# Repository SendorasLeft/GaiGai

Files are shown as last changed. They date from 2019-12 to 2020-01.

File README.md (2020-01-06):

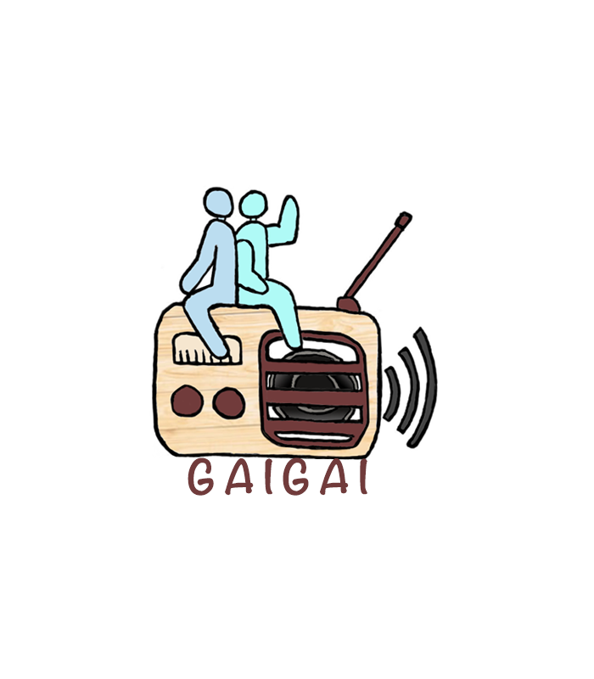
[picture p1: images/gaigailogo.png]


# GaiGai: A Radio for the Soul

Listen. Reconnect. Empower.

## The Team

Hello! We are Team GaiGai, consisting of:

- Yijie (Computer Science)
- Yong Hao (Materials Science & Engineering)
- Sharon (Pharmacy)
- Yong Kuan (Engineering Science Programme)

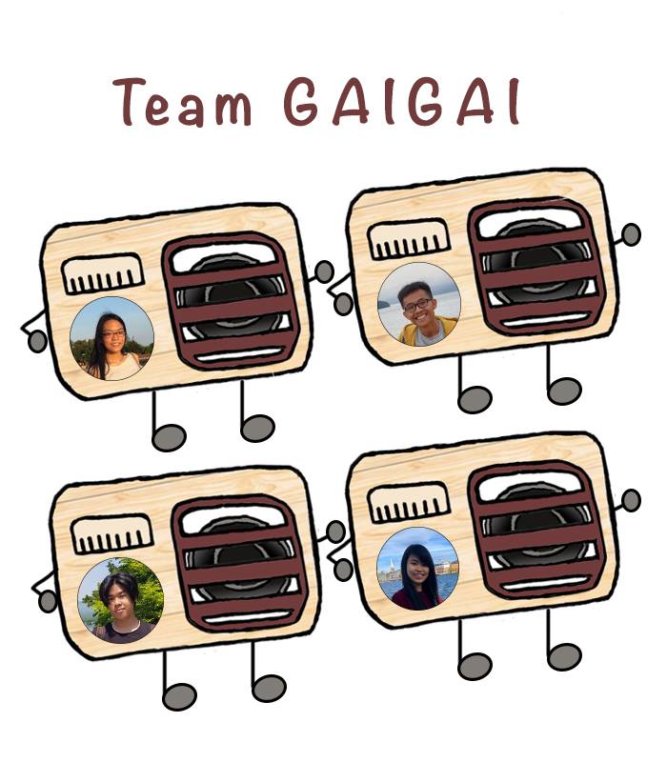
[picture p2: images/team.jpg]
team


## What is our purpose?

Our creation, the **GaiGai Radio**, aims to bridge the social gap between isolated
elderlies and their communities by gently surrounding them with the sounds of
a bustling community. Even if they live alone, this radio
ensures that they will never again be subject to the crippling silence of
solitude within their own homes.

## What exactly is the GaiGai Radio?



The GaiGai Radio is exactly what it sounds like - it's a radio that live-streams
various channels for the user to tune in to. But here's the twist: instead of
just listening to radio stars broadcasting their one-man shows, **everyone** who has a GaiGai Radio
can choose to participate in these streams. From everyday sounds to conversation or jokes,
these radios provide a platform for elderlies to reach out or keep in touch with others
who may be living near them. Over time, these radios aim to provide a stress-free
and convenient way to help isolated elderlies open up to their nearby communities, integrating them
back into society.

This radio:

- lets an elderly tune in to all available channels on a local server
- enables him / her to broadcast their own voice over the current channel
- is highly portable and can be easily carried around
- respects your privacy: the microphone can be easily muted with a click of a button!
- is fully anonymous and provides encryption over TCP-based VoIP communication servers
- **does not actually need to be in the form of a radio at all!** We provide an alternative
  way to simply run it using any computer with the correct dependencies

And most of all, everything from the hardware to software is entirely open-source, and easy to make.

## How does it work?

The GaiGai radio functions through a server-client architecture: in the public implementation, once
a radio is turned on, it first seeks out a central server to query for all available nearby servers
in the radio's vicinity. Thereafter, once it receives a suitable server, it attempts to connect and
tunes the user into the first available channel. The streaming is handled via an open-source
VoIP implementation known as [Murmur](https://github.com/mumble-voip/mumble/tree/master/src/murmur),
and streaming is done using TCP to the client radio.

To simplify things for this setup guide, however, we will teach you how to create your own server and radio from scratch. The
radio will then directly connect to the server, which can be run on any suitable computing device.

## How do I make my own GaiGai Radio?

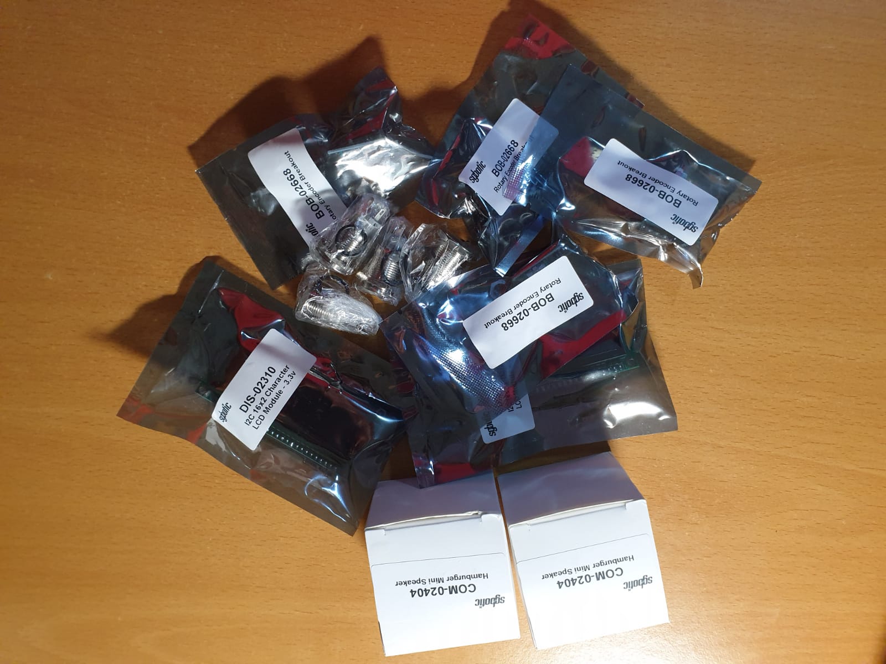
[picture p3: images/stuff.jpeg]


### Components

For a physical radio, you will need the following:

- 1 x Raspberry Pi Model 3 B
- 2 x Rotary encoders (One for the volume button, one for switching channels)
- 2 x 5V latching buttons (Power on/off switch, microphone mute)
- 1 x I2C LCD screen
- 1 x Jack-in Speaker
- 1 x Breadboard
- 1 x Blu Tack
- 1 x External PowerBank
- 1 x USB Microphone (we recommend using a [boundary or conference microphone](https://en.wikipedia.org/wiki/Boundary_microphone))
- Velcro, tape, and foam to hold the internal components together
- A 3D printer for the external casing (or some cardboard crafting skills!)
- (Optional) Acrylic paint, to jazz up the radio's exterior
- (Optional) Small pouch to hold the microphone if your chosen mic is limply wired, or if you opt for
  earphones
- (Optional) Velcro and slingband to act as a handle / strap for carrying the radio around

For the server, you will need the following:

- Minimally, a local network for hosting streams
- A computing device to run as the server. In this case, we use another Raspberry Pi 4 to fulfill this role.
- Internet connection, if hosting the server over the internet

### Physical Casing

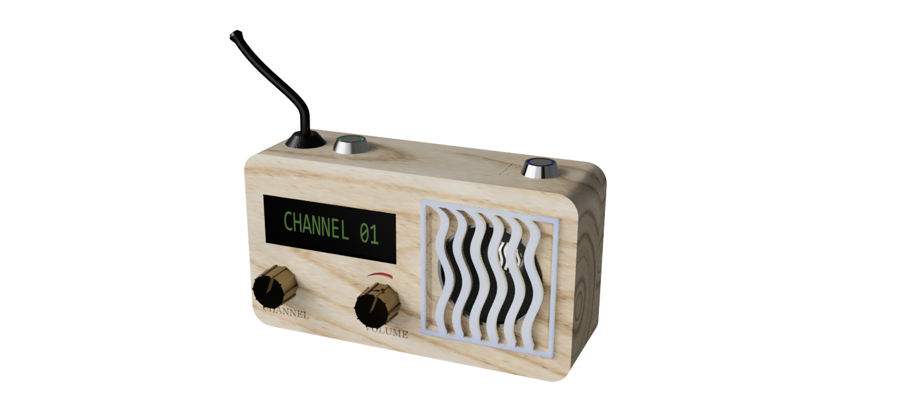
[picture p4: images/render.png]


We have released the STL files that we used for 3D-printing the exterior radio casing in the
[GitHub repository](https://github.com/SendorasLeft/GaiGai). Do feel free to use them, or modify
as necessary based on your chosen hardware dimensions. These files contain CAD models for the following:

- Front Casing
- Back Casing
- Rotary Knob Casings

If a
3D printer is not available, you may also make them out of other materials like cardboard.
(We do actually have a very decent alternate version of the radio
that was made from cardboard, so we're not pulling your leg here)

After making the case, put your artistic skills to the test by decorating the case!
We personally recommend a wooden texture.

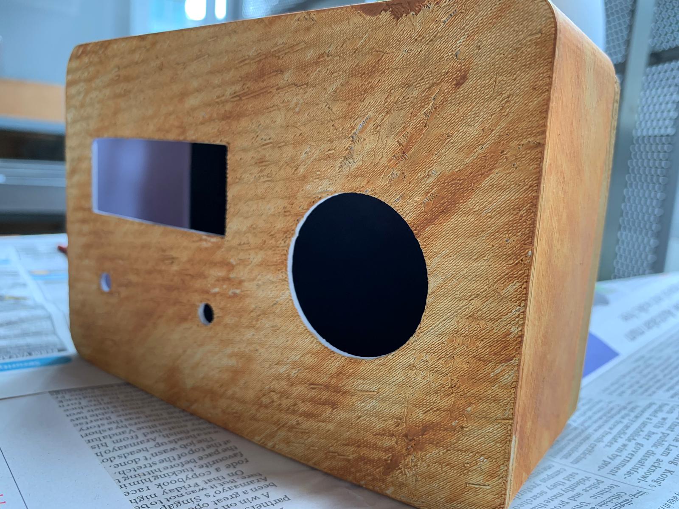
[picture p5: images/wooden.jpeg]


### Hardware Connections

We first need to wire up all the necessary components. Here is a full connection diagram you can follow
for the rotary encoders and latching buttons used for the radio:

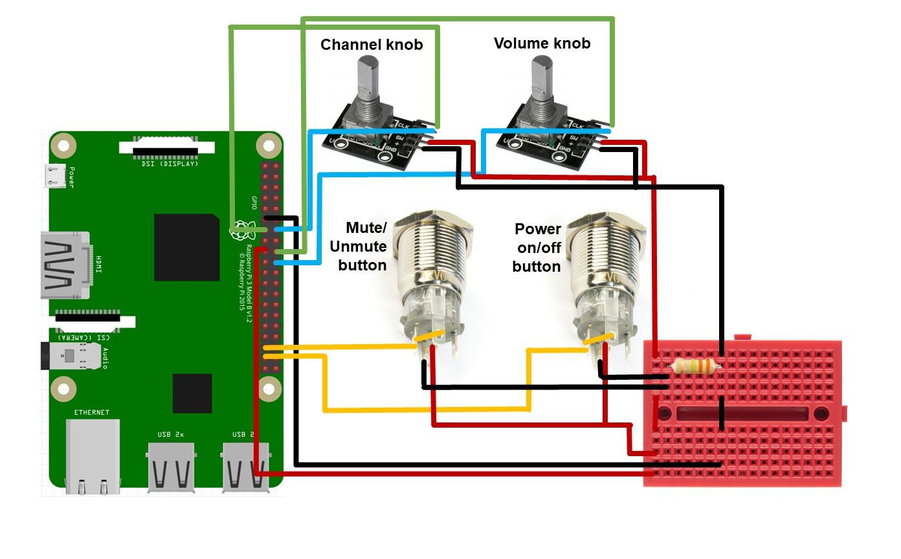
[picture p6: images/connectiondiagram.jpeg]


In addition, we also need to set up the connections for the LCD screen. This portion
is going to be a little more complicated, but you can
You can follow [this
instructive guide](http://www.circuitbasics.com/raspberry-pi-i2c-lcd-set-up-and-programming/).

The connection diagram for the I2C LCD screen should look like the following. This can differ depending on your
exact model.

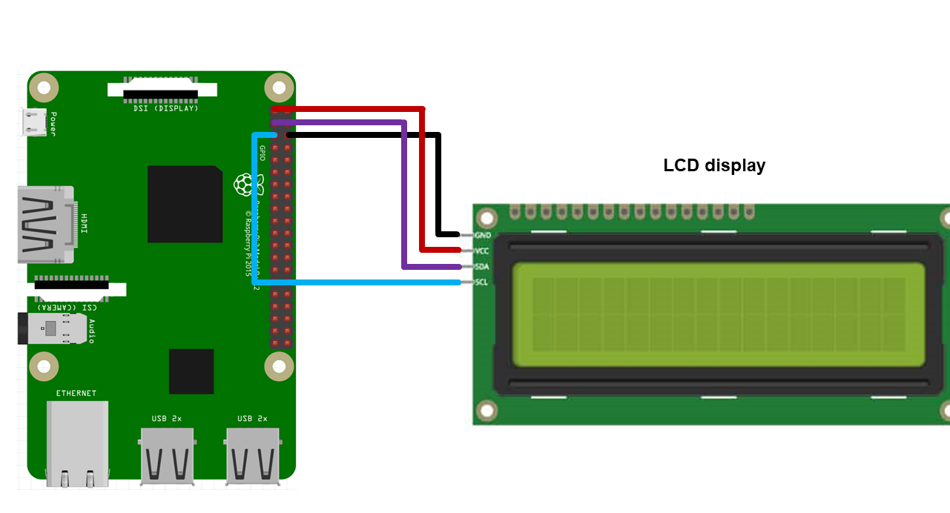
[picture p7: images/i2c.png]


Lastly, remember to connect up your chosen microphone and speaker.

### Setting up the Server

**Pre-requisites:**

- A Raspberry Pi with a flashed OS. If you're not sure how to do this step,
  the Raspberry Pi Foundation has a great
  starting guide [here](https://www.raspberrypi.org/downloads/). Alternatively, you may also wish to check
  out the [Murmur](https://github.com/mumble-voip/mumble/tree/master/src/murmur) documentation if you want
  to set up the server on an alternate computing device.
- Connect to a suitable WiFi / ethernet port with local network or internet access

**Set up the server:**

1. First, install the server dependencies by running `sudo apt-get install mumble-server`
2. Then, configure the autostart daemon by typing: `sudo dpkg-reconfigure mumble-server`. Choose yes to the following:
   - "AutoStart": Boot server on Pi startup
   - "High Priority": Dedicate available resources to running the server if possible
   - "SuperUser": Enables the `SuperUser` admin account, which can help you to configure the server
3. Find out the ip address of your Pi. (Use the `ifconfig` command to help you)
4. Set the password for the admin account `SuperUser`
   - run `sudo /usr/sbin/murmurd -ini /etc/mumble-server.ini -supw <password>`
5. Thereafter, configure your server details by running `sudo nano /etc/mumble-server.ini`
   - There are many things you can configure here. If you have time, we recommend that you take
     a good look through many of the variables in this file since they are pretty self-explanatory and offer
     some powerful customizations over the server. We suggest a few important ones below:
   - `Ctrl+W`, then type `mumble server` to jump to the relevant section. Uncomment it and replace with
     the name of your server
   - `Ctrl+W`, then type `port` to locate the relevant section. By default the server will be started on
     port `64738`. Change this if you wish to host the server on a different port (make sure you avoid the reserved ports!)
   - `Ctrl+W`, then type `channel`to locate the relevant section. This is where you can default channels to the server.
6. Finally, run `sudo /etc/init.d/mumble-server restart` to restart the server with the new settings. If all of
   the above was followed, the server should start anytime the Raspberry Pi is switched on.
7. (Optional) Set up port forwarding for global internet access to your server. Look up the instructions for your router model, and forward all messages
   from your desired port to the IP address of the mumble server (which should have been discovered Step 3)
8. (Optional) Login as the SuperUser admin account to configure the server via [Mumble](https://www.mumble.com/mumble-download.php). This is for those
   who don't like to browse through the configuration settings in Step 5.

### Setting up the Radio Software Backend

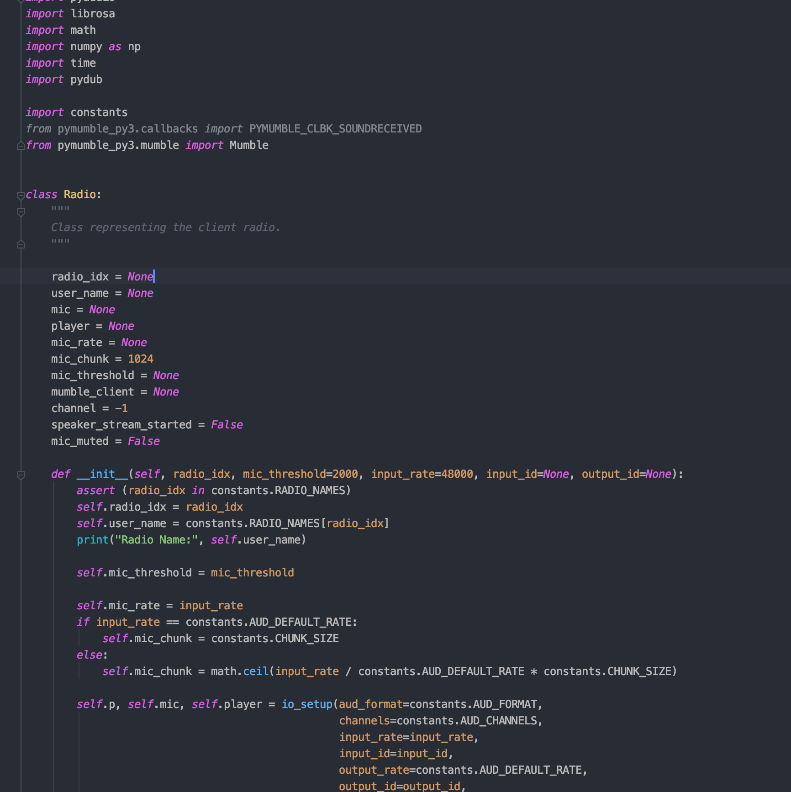
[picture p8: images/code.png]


**Pre-requisites:**

- A Raspberry Pi 3 Model B with a flashed OS. If you're not sure how to do this step,
  the Raspberry Pi Foundation has a great
  starting guide [here](https://www.raspberrypi.org/downloads/).

Note: For simplification in this setup guide, we hard-code the the server details in `constants.py`.
Change them there if required (for example, if you set a different port or IP for your server). This
guide assumes that five channels were created on the server.

**Install Dependencies:**
Here, we install all packages needed to run the radio.

- Update package lists
  - `sudo apt-get update`
  - `sudo apt-get dist-upgrade`
- PortAudio (purpose: audio streaming)
  - `sudo apt-get install libasound-dev`
  - `sudo apt-get install portaudio19-dev`
- PyAudio (purpose: audio streaming)
  - `sudo pip3 install pyaudio`
  - `sudo apt-get install python3-pyaudio`
- librosa (purpose: audio resampling & compression)
  - `sudo apt install libblas-dev llvm python3-pip python3-scipy`
  - `sudo apt install python3-protobuf`
  - `sudo pip3 install numpy --upgrade`
  - `sudo apt-get install python3-pandas`
  - `sudo apt-get install python3-sklearn`
  - `sudo apt-get install libatlas-base-dev`
  - `sudo pip3 install librosa==0.4.2`
- pydub (purpose: audio stream mixing)
  - `sudo pip3 install pydub`
- pyalsaaudio (purpose: volume control)
  - `sudo pip3 install pyalsaaudio`

**NOTE: Do not install or clone the pymumble library directly. We use a slightly modified version of
the written pymumble API for efficiency, which is included in this repository itself.**

**Clone the repository:**

Of course, we need to get the actual radio scripts for our radio. Here, we clone
it into the home directory of the Raspberry Pi.

- `cd ~`
- `git clone https://github.com/SendorasLeft/GaiGai`

**Headless setup:**

Since the Raspberry Pi will run inside the radio, it does not need to boot into
a fancy GUI. Here are the steps that will allow it to boot directly into the terminal:

- `raspi-config`
- Go to Boot Options, then select the option to boot into terminal **without** a password

**Run radio script on startup:**

Finally, we configure the python3 script to run on startup. There are many ways to do this, but
the simplest way is to add it to your bashrc confiuration file, since we're starting the RPi in
headless mode anyway.

- `echo "sudo python3 ~/GaiGai/driver_client.py <RADIO_IDX>" >> ~/.bashrc`
- Note: Replace `<RADIO_IDX>` above with an integer from 0 to 5. You can add more IDs via
  the `constants.py` file.

**Alternative: Run on Linux computer without hardware**

We provide a simplified script to start the radio on a computer if you do not wish to start
up the hardware. Note that at this point, the script does not support hardware functions like
channel switching or volume control etc. - To start the script, run `python3 driver_pc.py <RADIO_IDX>`

And you're done with the RPi software setup! The only thing left to do now is to bring it all together.

### Bringing It Altogether

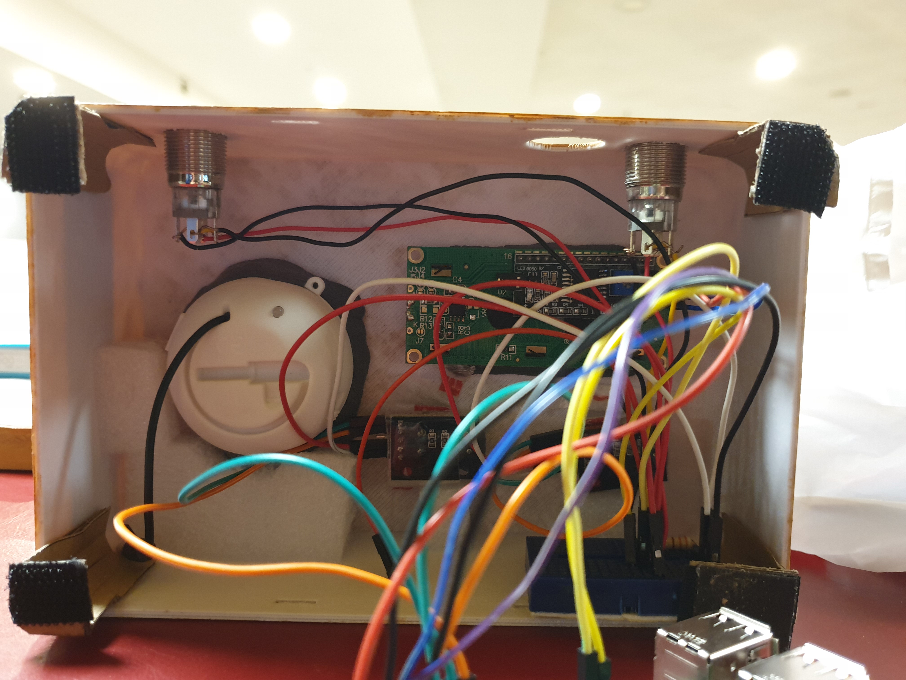
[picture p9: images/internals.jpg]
internals


Fit all the electronics within the case. There really isn't much we can do to guide you here, but
here are a few tips:

- Use blu-tack to fit the electronic components like the LCD screen or latching buttons
  into their grooves
- Use a layer of acrylic tape to hold electronics down after they are secured
- Use packing foam to further support the electronics and fill up empty spaces
- Use Velco with cardboard to create latching handles for the back case to attach to the front
- Fit all the electronic accessories inside first, then connect them to the Raspberry Pi towards the end.
- Don't forget to connect the power bank, microphone, and speaker before you close up the radio.
- (Optional) Use Velcro to tape on a suitable strap for carrying the radio around!
- (Optional) Use Velcro to tape on a suitable back pouch at the backc of the radio for holding small items

And there you have it, your own **GaiGai Radio**!

showcase

## Credits

This project is licensed under the [GNU General Public License v3.0](LICENSE).

We would also like to thank the maintainers of the open-source VoIP server project
[Murmur / Mumble](https://github.com/mumble-voip/), as well as its corresponding [client-side
python library](https://github.com/azlux/pymumble) which was started by [Robert904](https://github.com/Robert904), and actively maintained by [azlux](https://github.com/azlux) in a fork.

Lastly, we would like to express our gratitude to NUS and the organizers of
[NUS Makerthon 2020](https://blog.nus.edu.sg/makerthon2020/competition-theme/), without
whom this project would not have been possible.

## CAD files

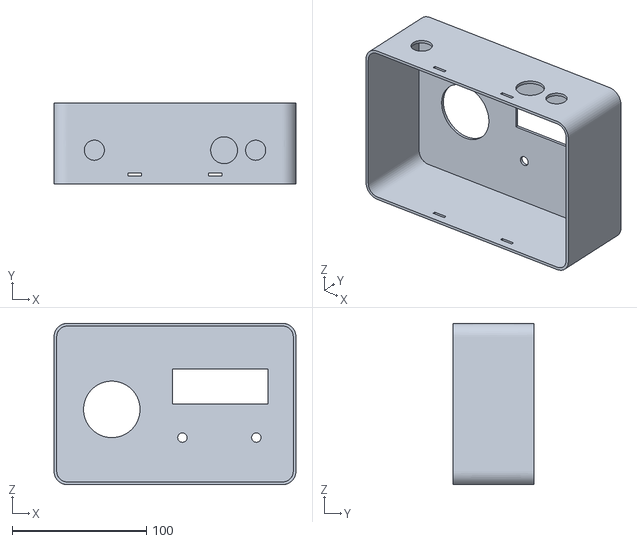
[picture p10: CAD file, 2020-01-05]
casing stl/radio_upsize_front.stl
180.0 x 60.0 x 120.0

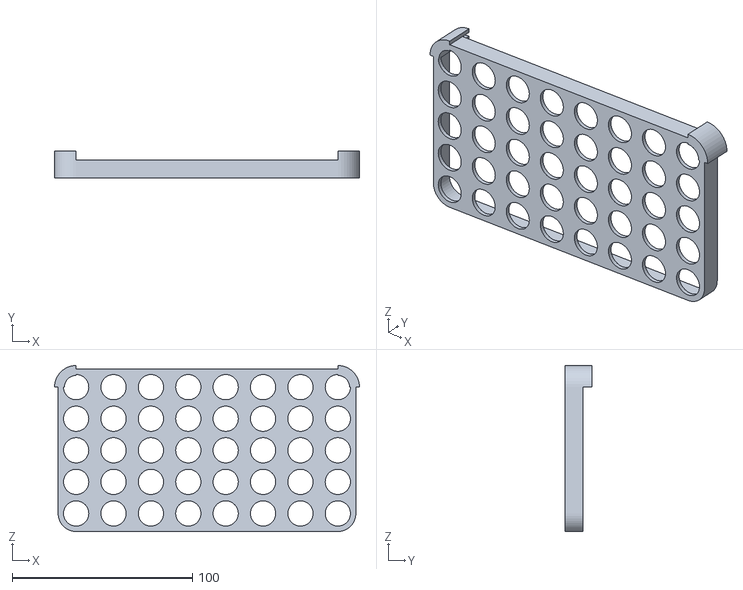
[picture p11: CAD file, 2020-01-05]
casing stl/radioback_v1.stl
169.0 x 15.0 x 92.0

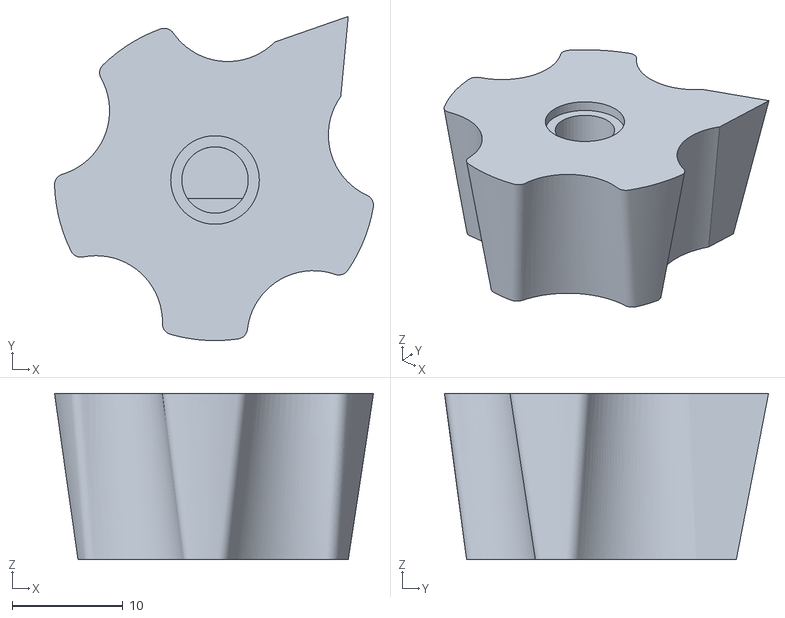
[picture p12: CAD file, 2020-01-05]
casing stl/radio_knob.stl
28.8 x 29.3 x 15.0

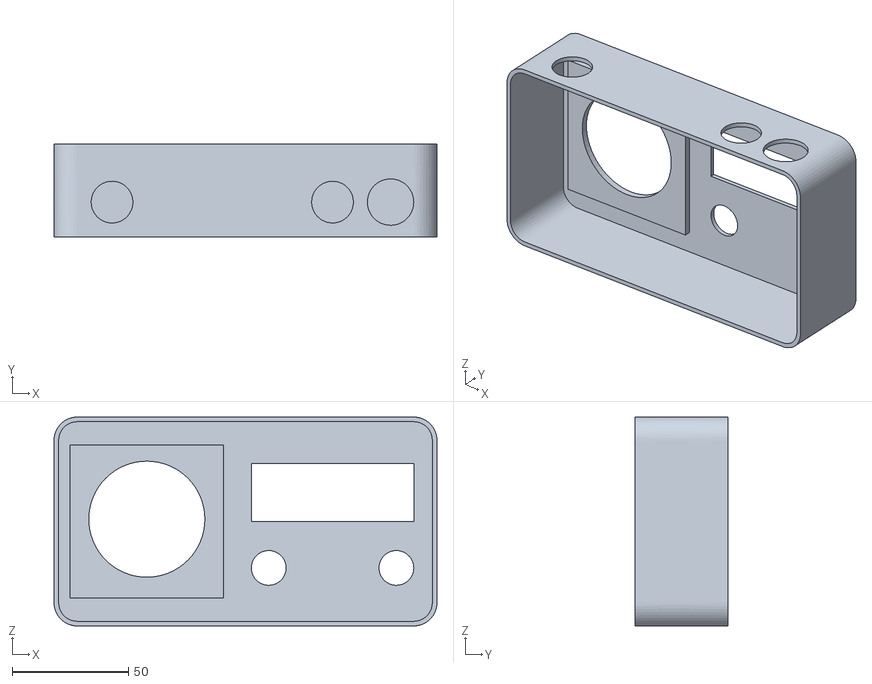
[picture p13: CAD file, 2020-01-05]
casing stl/radiofront_v1.stl
165.0 x 40.0 x 90.0

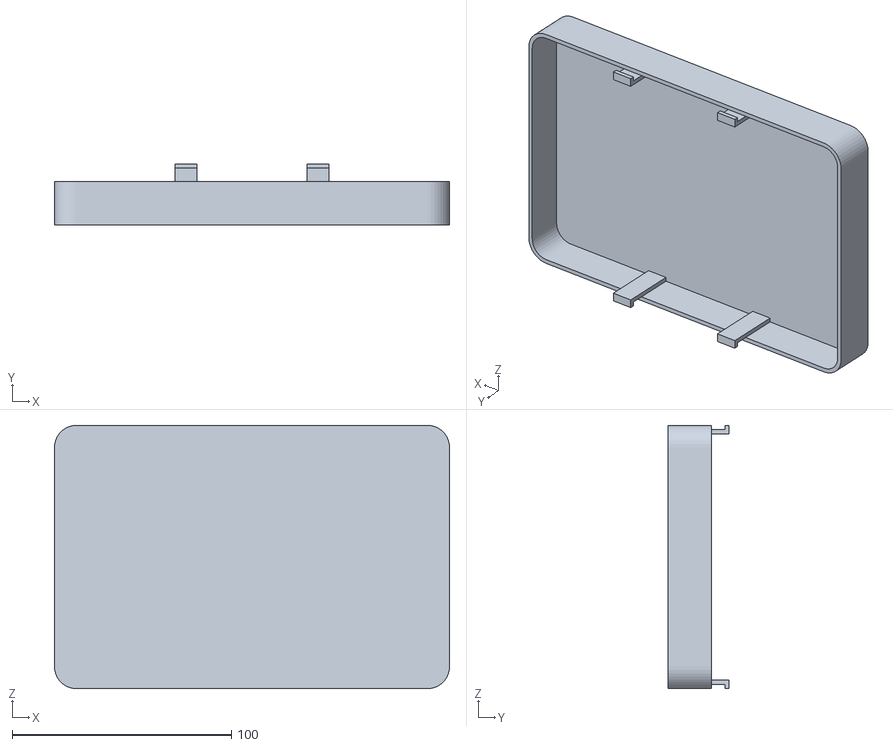
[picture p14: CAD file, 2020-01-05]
casing stl/radio_upsize_back.stl
180.0 x 28.0 x 120.0

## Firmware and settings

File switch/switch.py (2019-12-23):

from RPi import GPIO
from time import sleep

def setup(button):
    GPIO.setmode(GPIO.BCM)
    GPIO.setup(button, GPIO.IN, pull_up_down=GPIO.PUD_DOWN)

def loop(button):
    lastState = False
    while True:
        buttonState = GPIO.input(button)
        if buttonState != lastState:
            if buttonState == True:
                print("Button Pressed...")
            else:
                print("Button not pressed...")
        lastState = buttonState
        sleep(0.2)

def endProgram():
    GPIO.cleanup()

def main():
    button = 19
    setup(button)
    try:
        loop(button)
    except KeyboardInterrupt:
        print("keyboard interrupt detected")
        endProgram()

if __name__ == '__main__':
    main()

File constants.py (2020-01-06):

import pyaudio
import wave
from collections import namedtuple

# radio_idx to username mappings
RADIO_NAMES = {
    1: "RadioOne",
    2: "RadioTwo",
    3: "RadioThree",
    4: "RadioFour",
    5: "RadioFive",
    6: "RadioSix",
    7: "RadioSeven"
}

CHANNELS = [1, 5, 3, 4, 6]

# pyaudio
AUD_FORMAT = pyaudio.paInt16
AUD_CHANNELS = 1
AUD_DEFAULT_RATE = 48000

# packet chunk
CHUNK_SIZE = 1024

# server details TODO: define new channels
ServerDetails = namedtuple("ServerDetails",
                           "password address port")
SERVERS = {
    0: ServerDetails(password="password",
                     address="192.168.43.130",
                     port=64738),
    1: ServerDetails(password="password",
                     address="192.168.43.130",
                     port=64738),
    2: ServerDetails(password="password",
                     address="192.168.43.130",
                     port=64738)
}

CHUNK = 1024

CH_POWERON = "./voice/chinese/poweron.wav"
CH_POWEROFF = "./voice/chinese/poweroff.wav"
CH_CHNL0 = "./voice/chinese/chnl0.wav"
CH_CHNL1 = "./voice/chinese/chnl1.wav"
CH_CHNL2 = "./voice/chinese/chnl2.wav"
CH_CHNL3 = "./voice/chinese/chnl3.wav"
CH_CHNL4 = "./voice/chinese/chnl4.wav"
CH_MUTE = "./voice/chinese/muted.wav"
CH_UNMUTE = "./voice/chinese/unmuted.wav"

EN_POWERON = "./voice/english/poweron.wav"
EN_POWEROFF = "./voice/english/poweroff.wav"
EN_CHNL0 = "./voice/english/chnl0.wav"
EN_CHNL1 = "./voice/english/chnl1.wav"
EN_CHNL2 = "./voice/english/chnl2.wav"
EN_CHNL3 = "./voice/english/chnl3.wav"
EN_CHNL4 = "./voice/english/chnl4.wav"
EN_MUTE = "./voice/english/muted.wav"
EN_UNMUTE = "./voice/english/unmuted.wav"

CHNL0 = [EN_CHNL0, CH_CHNL0]
CHNL1 = [EN_CHNL1, CH_CHNL1]
CHNL2 = [EN_CHNL2, CH_CHNL2]
CHNL3 = [EN_CHNL3, CH_CHNL3]
CHNL4 = [EN_CHNL4, CH_CHNL4]

# BILINGUAL NOTIFICATION
POWERON = [EN_POWERON, CH_POWERON]
POWEROFF = [EN_POWEROFF, EN_POWEROFF]
CHNLS = [CHNL0, CHNL1, CHNL2, CHNL3, CHNL4]
MUTE = [EN_MUTE, CH_MUTE]
UNMUTE = [EN_UNMUTE, CH_UNMUTE]

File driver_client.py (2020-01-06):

import sys

from threading import Thread
from multiprocessing import Process
from time import sleep, time
from RPi import GPIO

from radio import Radio
# from knob.rotary_encoder import volume_main
import RPI_I2C_driver
# from lcd.channel_display import controlChannel

from gpiozero import Button
from knob.vol_control import changeVol, getVol
from knob.channel_control import changeChannel
from lcd.formatString import formatString
from switch.lcd_start_stop import display
from constants import *

INPUT_RATE = 48000
INPUT_ID = None
OUTPUT_ID = None

MIC_THRESHOLD = 2000

# rotary encoder
VOL_PIN_A = 23
VOL_PIN_B = 24

CHNL_PIN_A = 17
CHNL_PIN_B = 18

# switch
POWER_PIN = 26
MUTE_PIN = 19

radio = None
lastUpdateTime = 0
channel = 0
screen = RPI_I2C_driver.lcd()
screen.backlight(0)
power = False # True

volControlA = Button(VOL_PIN_A, pull_up=True)
volControlB = Button(VOL_PIN_B, pull_up=True)
chnlControlA = Button(CHNL_PIN_A, pull_up=True)
chnlControlB = Button(CHNL_PIN_B, pull_up=True)


def write_status():
    screen.lcd_display_string("Vol:"
                              + str(getVol()), 2)

def volcw():
    if power == True and volControlA.is_pressed:
        # print("1")
        changeVol(1)

def volccw():
    if power == True and volControlB.is_pressed:
        # print("-1")
        changeVol(0)

def chnlcw():
    global lastUpdateTime, channel
    if power == True and chnlControlA.is_pressed:
        print("1")
        newChnl = changeChannel(1, channel) # return channel number
        lastUpdateTime = time()
        channel = newChnl
        screen.lcd_display_string(formatString("Channel " + str(newChnl)), 1)
        # radio.change_channel(newChnl)
        

def chnlccw():
    global lastUpdateTime, channel
    if power == True and chnlControlB.is_pressed:
        print("-1")
        newChnl = changeChannel(0, channel) # return channel number
        lastUpdateTime = time()
        channel = newChnl
        screen.lcd_display_string(formatString("Channel " + str(newChnl)), 1)
        # radio.change_channel(newChnl)

# power on off
def switchedOn():
    global power
    print("on")
    display(1)
    radio.play_bilingual_notification(POWERON)
    power = True

def switchedOff():
    global power
    print("off")
    display(0)
    radio.play_bilingual_notification(POWEROFF)
    power = False
    
def muteMic():
    if power == True:
        radio.mute_mic()
        radio.play_bilingual_notification(MUTE)
    
def unmuteMic():
    if power == True:
        radio.unmute_mic()
        radio.play_bilingual_notification(UNMUTE)

# def GPIOsetup(clk, dt):
#     GPIO.setmode(GPIO.BCM)
#     GPIO.setup(clk, GPIO.IN, pull_up_down=GPIO.PUD_DOWN)
#     GPIO.setup(dt, GPIO.IN, pull_up_down=GPIO.PUD_DOWN)

def main(radio_idx):
    global radio
    radio = Radio(int(radio_idx),
                  mic_threshold=MIC_THRESHOLD,
                  input_rate=INPUT_RATE,
                  input_id=INPUT_ID,
                  output_id=OUTPUT_ID)

    # initialize volume control
    # volume_thread = Thread(target=volume_main)
    # volume_thread.start()
    #
    # channel_selection_thread = Thread(target=channel_selection)
    # channel_selection_thread.start()

    # power button
    powerButton = Button(POWER_PIN, pull_up=False)
    # mute button
    muteButton = Button(MUTE_PIN, pull_up=False)

    powerButton.when_pressed = switchedOn
    powerButton.when_released = switchedOff
    muteButton.when_pressed = unmuteMic
    muteButton.when_released = muteMic
    
    # assign functions for change volume
    volControlB.when_pressed = volcw
    volControlA.when_pressed = volccw

    # assign functions for change channel
    chnlControlB.when_pressed = chnlcw
    chnlControlA.when_pressed = chnlccw

    radio.connect(server=0)
    radio.start_speaker_stream()

    #print("play poweron")
    #radio.play_bilingual_notification(POWERON)

    while True:
        radio.stream_mic_segment_to_server()
        # print("curr", radio.get_current_channel())
        # print("new", channel)
        # print("now", time())
        # print("last", lastUpdateTime)
        if radio.get_current_channel() != channel and time() - lastUpdateTime > 1:
            # print("changing channel...")
            radio.change_channel(channel)
            radio.play_bilingual_notification(CHNLS[channel])
        #write_status()


if __name__ == "__main__":
    if len(sys.argv) < 2:
        print("Usage: python3 driver_client.py <radio_idx>")
        sys.exit(0)
    main(sys.argv[1])

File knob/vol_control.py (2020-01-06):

# Install command for alsaaudio:
# sudo -H pip3 install pyalsaaudio

import alsaaudio

def getVolumeChange(vol):
    if vol == 0:
        return 25
    elif vol >= 94:
        return 1
    elif vol >= 90:
        return 2
    elif vol >= 80:
        return 3
    elif vol >= 70:
        return 4
    elif vol >= 55:
        return 5
    else:
        return 7

def incrVol(mixer):
    vol = mixer.getvolume()[0]
    if vol >= 97:
        return vol
    if vol + getVolumeChange(vol) > 97:
        return 97
    return vol + getVolumeChange(vol)
        
def decrVol(mixer):
    vol = mixer.getvolume()[0]
    if vol == 0: # muted
        return 0
    if vol <= 25: # can't go below 25 cos it will be too soft
        return vol
    if vol - getVolumeChange(vol) < 25:
        return 0
    return vol - getVolumeChange(vol)


# val = 1 to increase, val = 0 to decrease
def changeVol(val):
    mixer = alsaaudio.Mixer(alsaaudio.mixers()[0])
    vol = mixer.getvolume()[0]
    if val == 1:
        vol = incrVol(mixer)
    else:
        vol = decrVol(mixer)
    mixer.setvolume(vol)
    print("volume set to", mixer.getvolume()[0])
    # str = formatString(vol) TODO


def getVol():
    mixer = alsaaudio.Mixer(alsaaudio.mixers()[0])
    return mixer.getvolume()[0]

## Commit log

2019-12-20 threaded udp client/server loop in single script
2019-12-20 removed print statement from threaded udp script
2019-12-20 attempt for multi device streaming
2019-12-20 switch to udp multicasting ports for future integration of multiple radios
2019-12-22 add basic switch file
2019-12-22 add basic rotary encoder file
2019-12-22 fix rotary encoder to adjust to sound capped between 0 to 95
    [rotary_encoder.py]
2019-12-22 fix switch code - using == instead of is
    [switch.py]
2019-12-22 adjust volume parameters for rotary encoder
2019-12-22 remove useless print statement
2019-12-23 test different version of switch
2019-12-23 modify new switch code
2019-12-25 Fixed all usages of select#select() for central udp implementation. added function comments for central.py
    [radio.py]
2019-12-26 Bug fix for radio socket time out
    [radio.py]
2019-12-28 Included workaround/fix for differing librosa#resample implementations across different installed versions
    [driver_client.py, radio.py]
2020-01-04 Volume thread
2020-01-04 add lcd things to driver client
2020-01-05 add switch code using gpiozero
2020-01-05 add channel stuff to driver_client
2020-01-05 complete channel switching - knob + lcd + radio
2020-01-05 modify driver
2020-01-05 add power button to driver
2020-01-05 prevent lcd lighting up unnecessarily
    [driver_client.py]
2020-01-05 attempt controlling channel switching
2020-01-05 Update docs
    [radio_knob.stl, radio_upsize_back.stl, radio_upsize_front.stl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]
2020-01-06 fix driver client
2020-01-06 driver client
